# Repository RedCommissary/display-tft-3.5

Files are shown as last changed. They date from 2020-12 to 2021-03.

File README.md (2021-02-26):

## Информационная панель на базе TFT ILI9488 3.5"

Простая HMI панель на базе микроконтроллера STM32 и TFT дисплея с диагональю 3.5", предназначенная для работы в составе различных радиоэлектронных устройствах для вывода различной графической информации. На плате так же установлен пьезокерамический узлучатель (buzzer) и имеется возможность подключить внешнюю клавиатуру через выведенные на разъем I/O, реализованы цепи аппаратного подавления дребезга контактов.

Вид сверху

>

Вид снизу

>

Клавиатура

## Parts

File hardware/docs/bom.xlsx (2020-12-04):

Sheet: HMI-TFT-3.5
Designator | Value | PartNumber | Manufacturer | Quantity | Comment | HelpURL
BF1 |  | MLT-7525 | Jiangsu | 1 | SMD, 7.5x7.5x2.5 mm, 2.7 kHz, 3.6VDC, 80dB, -20...+70°C | https://lcsc.com/product-detail/Buzzers_Jiangsu-Huaneng-Elec-MLT-7525_C95299.html
C1, C7, C9, C10, C11, C12, C13, C15, C16, C17, C18 | 4.7μF | CL10B475KQ8NQNC | Samsung | 11 | Ceramic capacitor, 4.7μF, X7R, ±10%, 6.3V, 603, -55...+125°C | https://www.digikey.com/en/products/detail/samsung-electro-mechanics/CL10B475KQ8NQNC/3887745
C2, C3, C4, C5, C6, C8, C14, C19 | 0.1μF | CL10B104KB8WPND | Samsung | 8 | Ceramic capacitor, 0.1μF, X7R, ±10%, 50V, 603, -55...+125°C | https://www.digikey.com/product-detail/en/samsung-electro-mechanics/CL10B104KB8WPND/1276-CL10B104KB8WPNDCT-ND/11488014
D1 |  | STM32F401CCU6 | STMicroelectronics | 1 | IC microcontroller, 32-Bit, Cortex-M4, 84MHz, 256KB, 64KB, 1.7...3.6V, -40...+85°C, 48-UFQFPN (7x7) | https://www.digikey.com/en/products/detail/stmicroelectronics/STM32F401CCU6/4755971
D2 |  | AP63200WU-7 | Diodes | 1 | DC/DC buck converter, input 3.8...32V, 500kHz, output 1.2...12V, 2A, -40...+85°C, SOT23-6 | https://www.digikey.com/en/products/detail/diodes-incorporated/AP63200WU-7/9858423
L1 | 4.7μH | CD32YP0302-4R7M | YJYCOIN | 1 | Fixed inductor, 4.7μH, ±20%, CD32 series, 1.5A, -40...+125°C | https://lcsc.com/product-detail/New-Arrivals_YJYCOIN-CD32YP0302-4R7M_C492259.html
R1, R2, R4, R8, R10, R12, R15, R20, R22 | 10k | RC0603JR-0710KL | Yageo | 9 | Resistor film, 10k, ±5%, 603, 0.1W, -55...+125°C | https://www.digikey.com/product-detail/en/yageo/RC0603JR-0710KL/311-10KGRCT-ND/729647
R3, R5, R6, R7, R9, R11, R14, R19, R21 | 120R | RC0603JR-07120RL | Yageo | 9 | Resistor film, 120R, ±5%, 603, 0.1W, -55...+125°C | https://www.digikey.com/product-detail/en/yageo/RC0603JR-07120RL/311-120GRCT-ND/729653
R13, R17 | 1k | RC0603JR-071KL | Yageo | 2 | Resistor film, 1k, ±1%, 603, 0.1W, -55...+125°C | https://www.digikey.com/en/products/detail/yageo/RC0603JR-071KL/726677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
R16 | 30k9 | RC0603FR-0730K9L | Yageo | 1 | Resistor film, 30k9, ±1%, 603, 0.1W, -55...+125°C | https://www.digikey.com/en/products/detail/yageo/RC0603FR-0730K9L/727144
R18 | 10k | AC0603FR-0710KL | Yageo | 1 | Resistor film, 10k, ±1%, 603, 0.1W, -55...+125°C | https://www.digikey.com/en/products/detail/yageo/AC0603FR-0710KL/2827814
VD1 |  | 150060VS75000 | Wurth | 1 | LED, 20mA, 2V, 603, -55...+150°C | https://www.digikey.com/product-detail/en/w-rth-elektronik/150060VS75000/732-4980-1-ND/4489904
VD2 |  | 150060YS75000 | Wurth | 1 | LED, 20mA, 2V, 603, -55...+150°C | https://www.digikey.com/product-detail/en/wurth-electronics-inc/150060YS75000/732-4981-1-ND/4489907
VD3 |  | MBR2H100SFT3G | ON Semiconductor | 1 | Schottky diode, 100V, 2A, 840mV, 15pF, SOD-123F, -55...+150°C | https://www.digikey.com/product-detail/en/on-semiconductor/MBR2H100SFT3G/MBR2H100SFT3GOSCT-ND/3462288
VT1, VT2 |  | IRLML0030TRPBF | Infineon Technologies | 2 | MOSFET N-channel transistor, 30V, 5.3A, 2.6nC, 1.3W, 27mOhm, 382pF, SOT-23, -55...+150°C | https://www.digikey.com/en/products/detail/infineon-technologies/IRLML0030TRPBF/2202215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
X1 |  | AFC07-S40ECC-00 | JUSHUO | 1 | Connector, 40pin, 0.5mm, FFC/FPC, Top contact | https://lcsc.com/product-detail/FFC-FPC-Connectors_JUSHUO-AFC07-S40ECC-00_C11097.html
X3 |  | CWF-4R | Connfly | 1 | Connector, 4pin, 2.54mm, 250VAC, 3A | https://www.chipdip.ru/product/cwf-4r-ds1069-4-mr
X4 |  | CWF-6R | Connfly | 1 | Connector, 6pin, 2.54mm, 250VAC, 3A | https://www.chipdip.ru/product/cwf-6r-ds1069-6-mr

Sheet: Keyboard
Designator | Value | PartNumber | Manufacturer | Quantity | Comment | HelpURL
SB1, SB2, SB3, SB4, SB5 |  | FSM2JSMAATR | TE Connectivity | 5 | Tactile button, 6x6mm | https://www.digikey.com/product-detail/en/te-connectivity-alcoswitch-switches/FSM2JSMAATR/450-1792-1-ND/3503931
X1 |  | CWF-6R | Connfly | 1 | Connector, 6pin, 2.54mm, 250VAC, 3A | https://www.chipdip.ru/product/cwf-6r-ds1069-6-mr

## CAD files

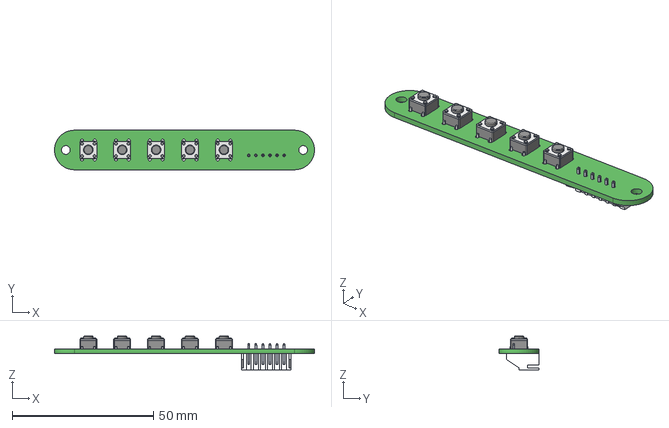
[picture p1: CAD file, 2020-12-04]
hardware/mechanical/3d-keyboard-pcb.step
92.0 x 14.0 x 12.0 mm

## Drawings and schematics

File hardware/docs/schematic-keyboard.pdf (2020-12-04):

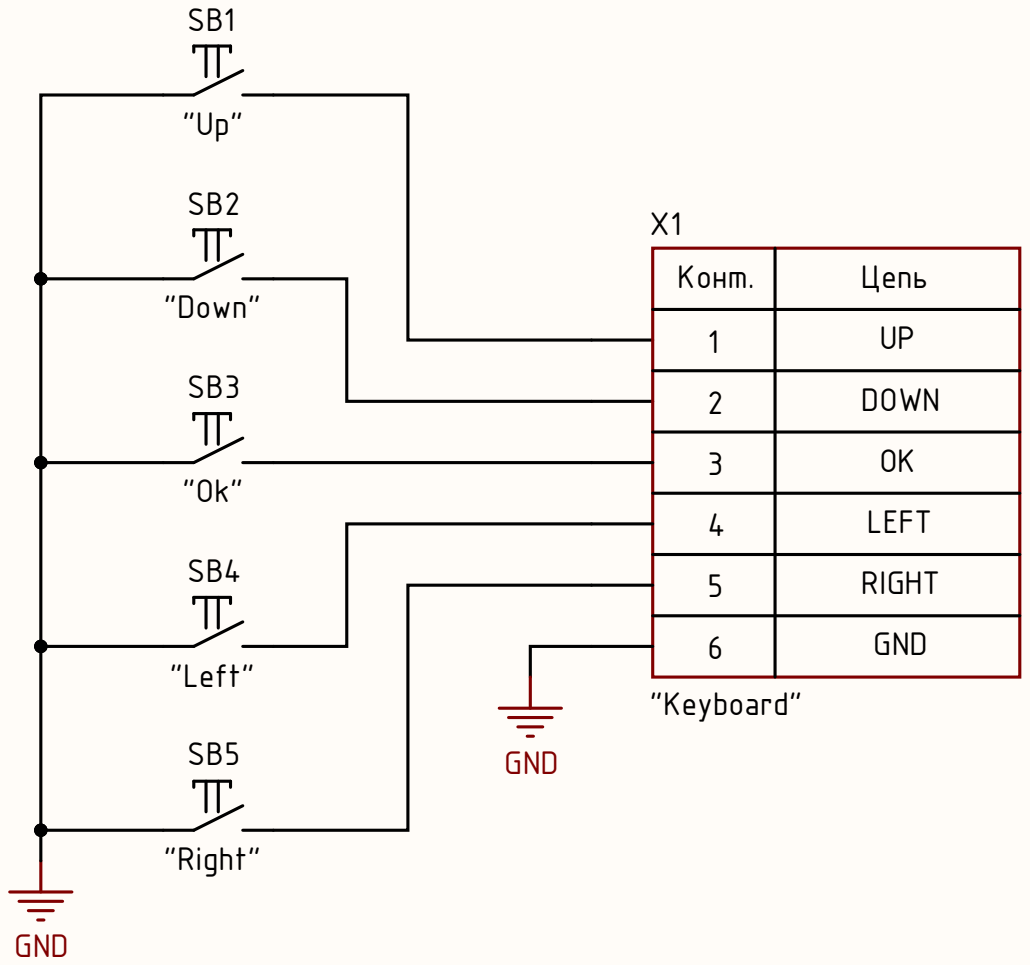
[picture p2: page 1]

"Keyboard" 12 Конт. | Цепь 3456 D O W N

Author Date | Ilya Galki n | Keyboard for HMI pannel with TFT display of 3.5"

Manufacturer Page Total pages

Materials Size page | A3

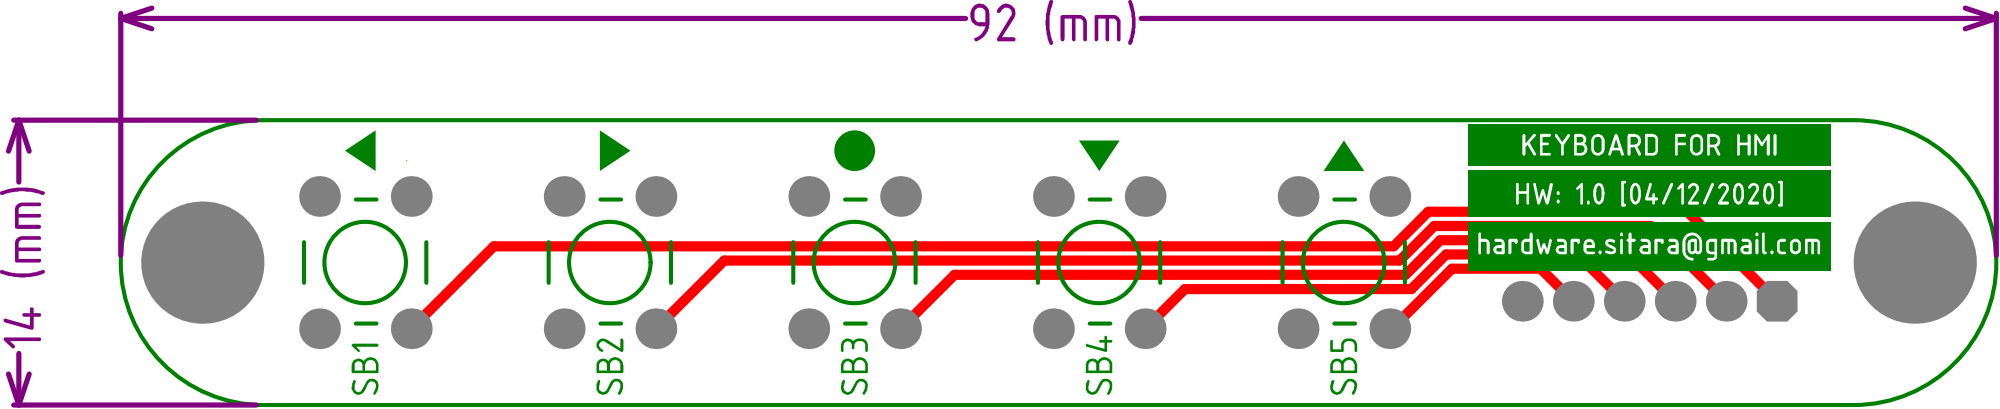
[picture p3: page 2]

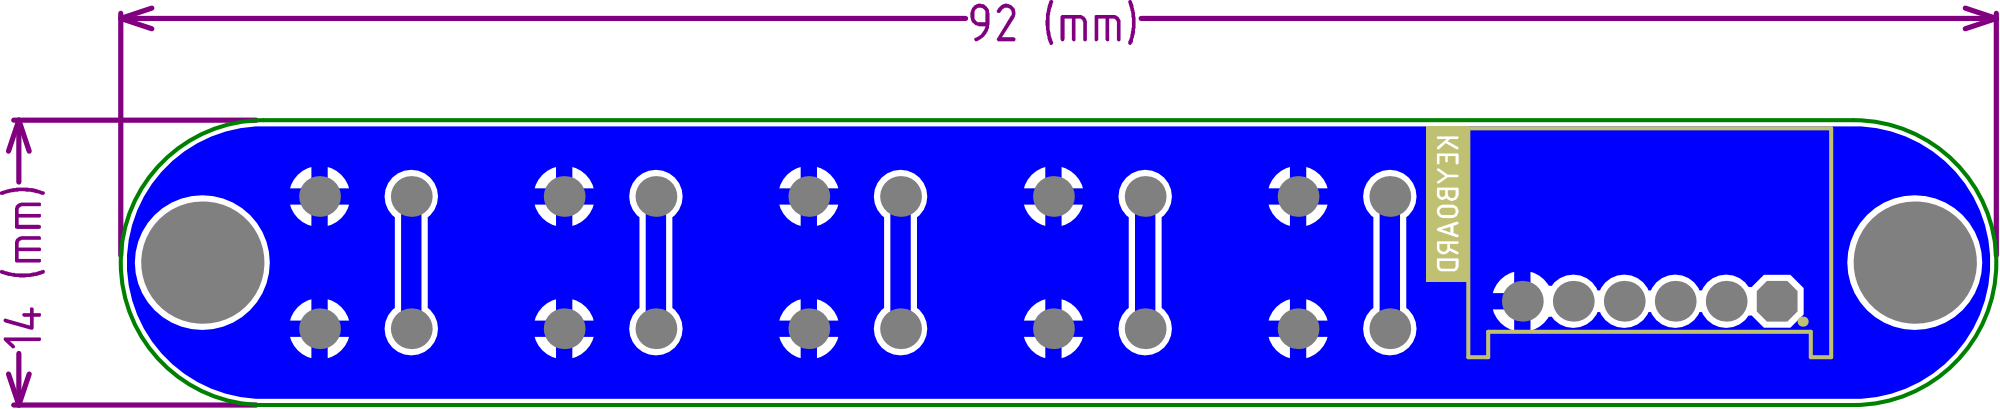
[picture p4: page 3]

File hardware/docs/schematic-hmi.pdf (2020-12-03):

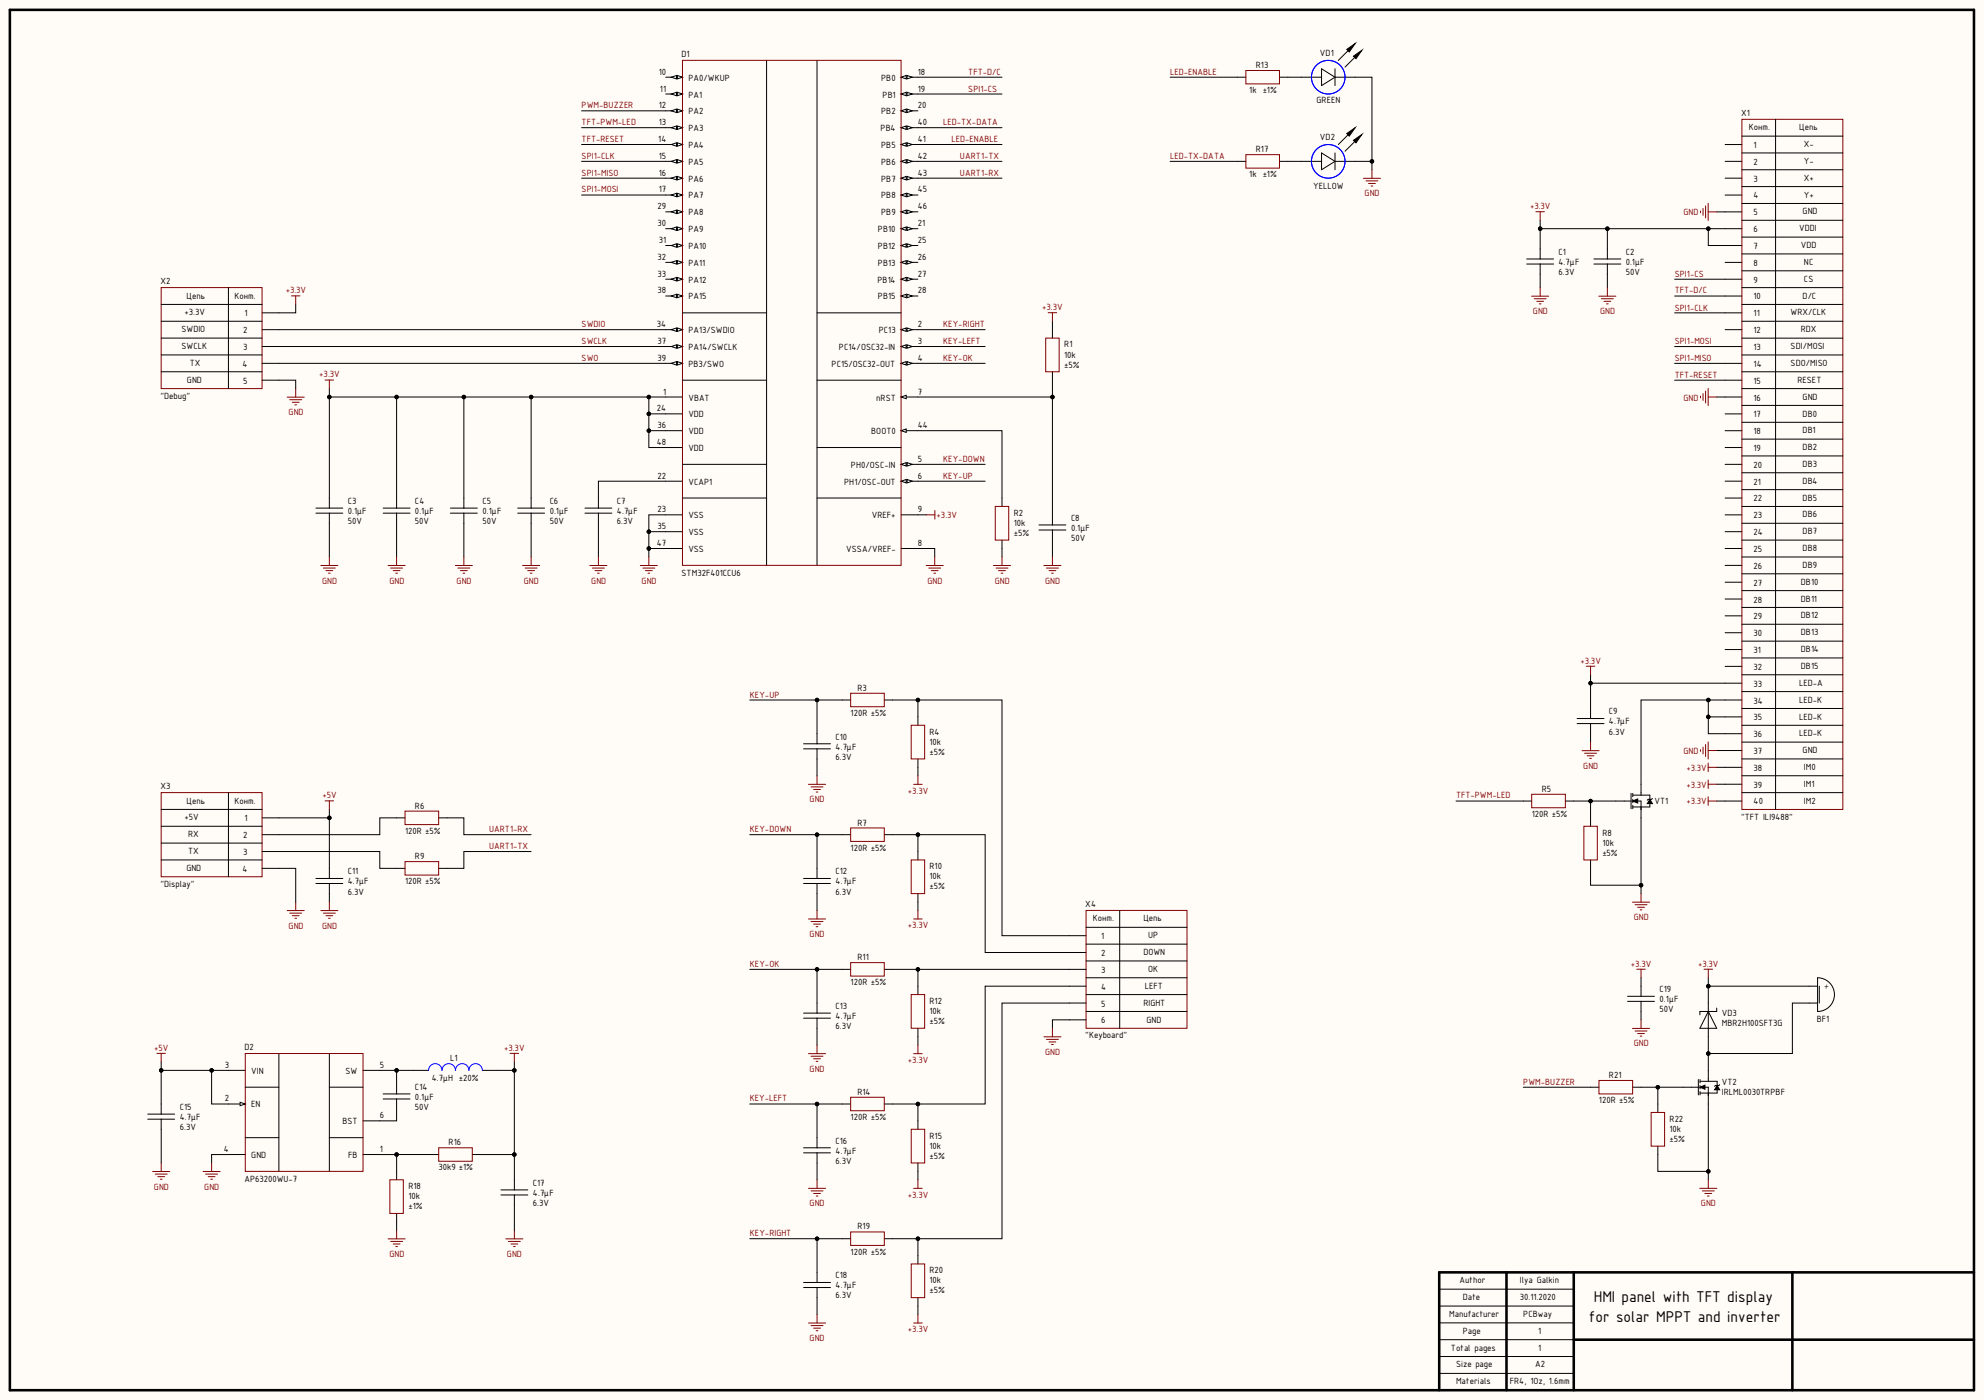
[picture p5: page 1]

Y+ GND

CSD/C

18 | WRX/CLK RDX SDI/MOSI SDO/MISO RESET GND DB0 DB1 DB2 DB3 DB4 DB5 DB6 DB7 DB8 DB9 DB10 DB11 DB12 DB13 DB14 DB15

KEY-LEFT KEY-RIGH

4 8 | 5 KEY-D OWN 6 KEY-U P

S 23 VS VS VS S | VREF+ VS SA/VREF-

33 | LED-A

34 | LED-K

+3.3V | 35 | LED-K

37 | LED-K GND IM0 IM1 IM2
36

38
3940

Цепь | Конт .

"Keyboard" 12 Конт. | Цепь 3456 D O W N

HMI panel with TFT display
for solar MPPT and inverter

Manufacturer Page Total pages

Materials Size page | A2

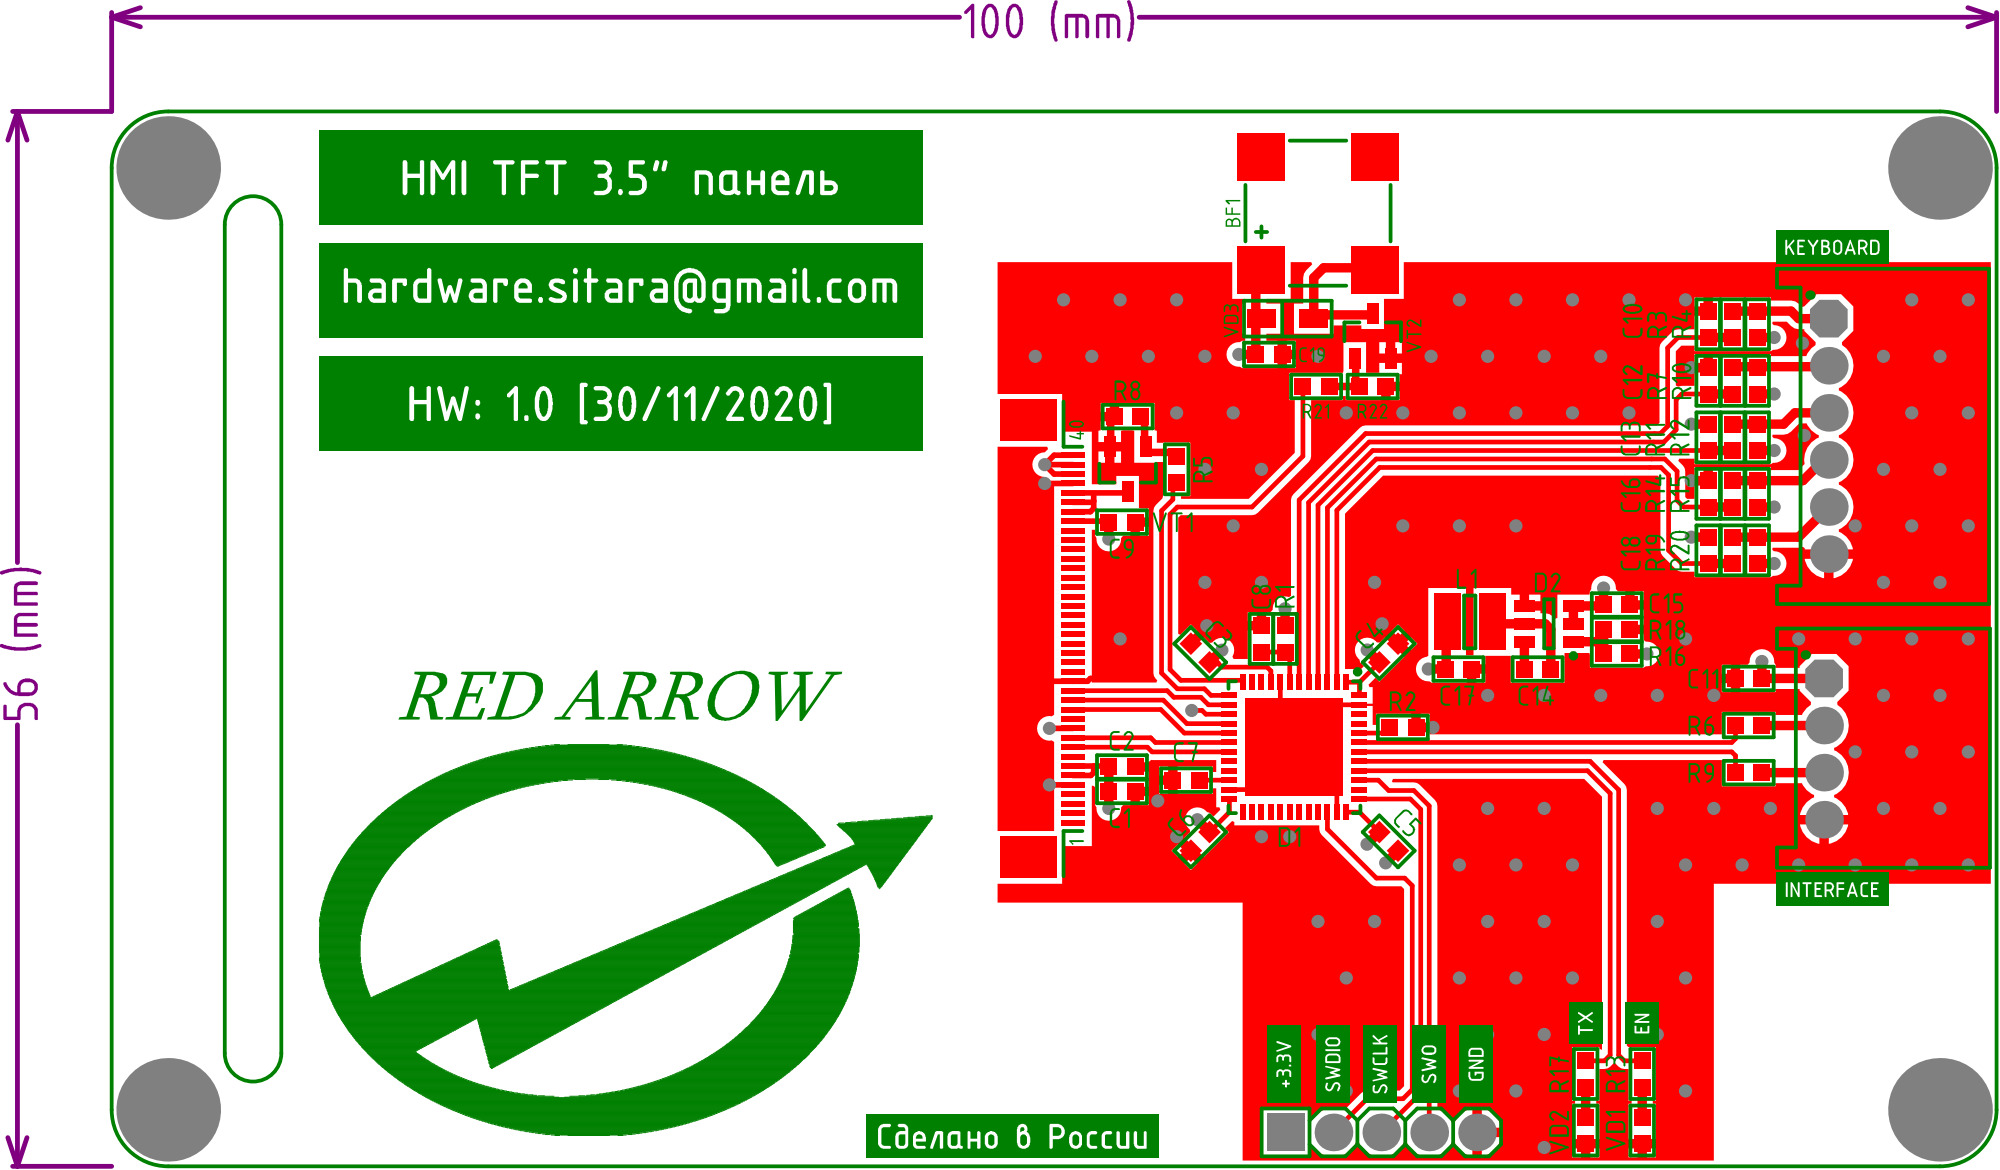
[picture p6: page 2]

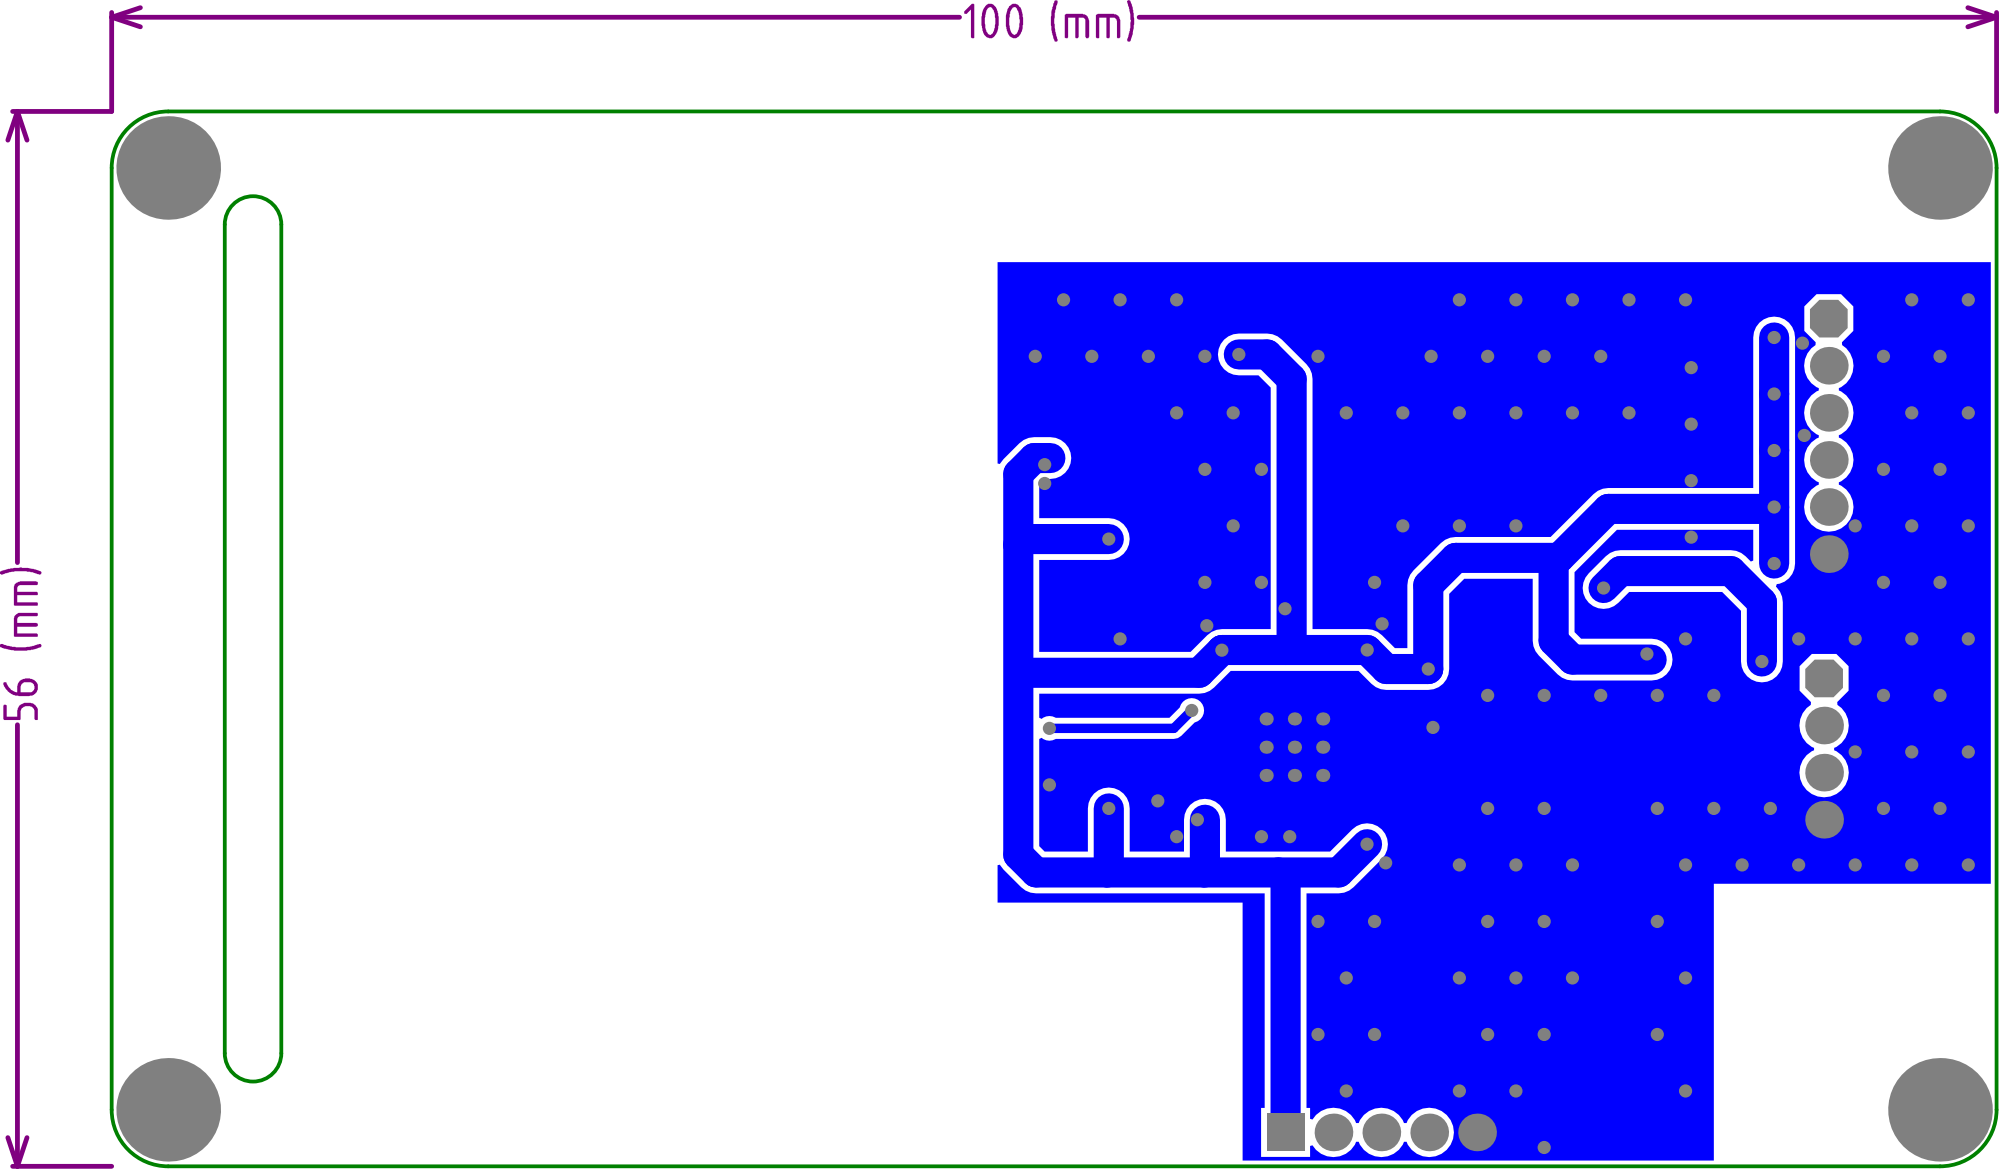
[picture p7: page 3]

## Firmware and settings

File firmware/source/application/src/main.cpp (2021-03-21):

/********************************************************************************
 * project     HMI panel of the MCU STM32F401CCU6 and TFT ILI9488 (SPI)         *
 *                                                                              *
 * file        main.cpp                                                         *
 * author      @RedCommissary                                                   *
 * date        10.02.2021                                                       *
 *                                                                              *
 ********************************************************************************/

/********************************************************************************
 * Include 
 ********************************************************************************/

#include "main.h"
#include "lvgl.h"
#include "ili9488.h"

void lv_port_disp_init();
void disp_flush (lv_disp_drv_t * disp_drv, const lv_area_t * area, lv_color_t * color_p);
void StartDisplayProcessing();
void lv_example_arc_1();

int main() {
    Application::Init();
    StartDisplayProcessing();

    lv_init();
    lv_port_disp_init();
    lv_example_arc_1();

    while(1){
        Delay::Set(5);
        lv_tick_inc(5);
    }
}

/********************************************************************************
 * Function
 ********************************************************************************/

void lv_port_disp_init() {
    ILI9488::Init();
    ILI9488::SetBrightness(80);

    static lv_disp_buf_t draw_buf_dsc;
    static lv_color_t draw_buf[LV_HOR_RES_MAX * 10];                          
    lv_disp_buf_init(&draw_buf_dsc, draw_buf, NULL, LV_HOR_RES_MAX * 10);   


    lv_disp_drv_t disp_drv;                         
    lv_disp_drv_init(&disp_drv);                    
    disp_drv.hor_res = 480;
    disp_drv.ver_res = 320;
    disp_drv.flush_cb = disp_flush;
    disp_drv.buffer = &draw_buf_dsc;
    lv_disp_drv_register(&disp_drv);
}

void disp_flush (lv_disp_drv_t * disp_drv, const lv_area_t * area, lv_color_t * color_p) {
    uint16_t xStart = area->x1;
    uint16_t xEnd = area->x2;
    uint16_t yStart = area->y1;
    uint16_t yEnd = area->y2;
    uint16_t color = lv_color_to16(*color_p);

    ILI9488::DrawFill(xStart, yStart, xEnd, yEnd, color);

    lv_disp_flush_ready(disp_drv);
}

/********************************************************************************
 * Display processing
 ********************************************************************************/

void StartDisplayProcessing() {
    RCC->APB1ENR |= RCC_APB1ENR_TIM3EN;     

    TIM3->PSC = 42-1;
    TIM3->ARR = 200;
    TIM3->DIER |= TIM_DIER_UIE;
    TIM3->CR1  |= TIM_CR1_CEN;

    NVIC_EnableIRQ(TIM3_IRQn);
}

void sTim3::handler (void) {
    TIM3->SR &= ~TIM_SR_UIF;
    lv_task_handler();
}

/********************************************************************************
 * Example for GUI
 ********************************************************************************/

void lv_example_arc_1() {
    lv_obj_t * arc = lv_arc_create(lv_scr_act(), NULL);
    lv_arc_set_end_angle(arc, 200);
    lv_obj_set_size(arc, 150, 150);
    lv_obj_align(arc, NULL, LV_ALIGN_CENTER, 0, 0);
}

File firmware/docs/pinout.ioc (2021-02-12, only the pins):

Mcu.UserName=STM32F401CCUx
PA13.Signal=SYS_JTMS-SWDIO
PA14.Signal=SYS_JTCK-SWCLK
PA2.GPIO_Label=TIM2-CH3-PWM-BUZZER
PA2.Signal=S_TIM2_CH3
PA3.GPIO_Label=TIM5-CH4-TFT-LED
PA3.Signal=S_TIM5_CH4
PA4.GPIO_Label=TFT-RESET
PA4.Signal=GPIO_Output
PA5.Signal=SPI1_SCK
PA6.Signal=SPI1_MISO
PA7.Signal=SPI1_MOSI
PB0.GPIO_Label=TFT-D/C
PB0.Signal=GPIO_Output
PB1.GPIO_Label=SPI1-CS
PB1.Signal=GPIO_Output
PB3.Signal=SYS_JTDO-SWO
PB4.GPIO_Label=LED-TX-DATA
PB4.Signal=GPIO_Output
PB5.GPIO_Label=LED-ENABLE
PB5.Signal=GPIO_Output
PB6.Signal=USART1_TX
PB7.Signal=USART1_RX
PC13-ANTI_TAMP.GPIO_Label=KEY-RIGHT
PC13-ANTI_TAMP.Signal=GPXTI13
PC14-OSC32_IN.GPIO_Label=KEY-LEFT
PC14-OSC32_IN.Signal=GPXTI14
PC15-OSC32_OUT.GPIO_Label=KEY-OK
PC15-OSC32_OUT.Signal=GPXTI15

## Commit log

2020-11-20 docs: Добавил даташит на контроллер дисплея ILI9488
2020-11-20 new: Запустил дисплей ILI9488, протестировал и определил схему
2020-11-30 new: Завершил принципиальную схему HMI панели
    [hmi-tft-3.5.PrjPcb, hmi.SchDoc, pcb.PcbDoc]
2020-11-30 new: Выполнил трассировку печатной платы, завершил проект
    [hmi-tft-3.5.PrjPcb, hmi.SchDoc]
2020-11-30 docs: Добавил pinout по схеме для микроконтроллера
2020-11-30 docs: Сгенерировал КД: схема, вом, 3d модель, gerber файлы
    [bom.xlsx]
2020-12-03 new: Добавил буззер в проект и выгрузил КД с изменениями
    [bom.xlsx, hmi-tft-3.5.PrjPcb, hmi.SchDoc]
2020-12-04 new: Завершил проект клавиатуры для HMI панели
    [hmi-tft-3.5.PrjPcb, hmi.SchDoc, keyboard-for-hmi.PrjPcb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]
2020-12-04 docs: Сгенерировал КД для клавиатуры: схема, вом, 3d модель, gerber файлы
    [3d-keyboard-pcb.step, bom.xlsx]
2021-02-10 new: Проверил новые HMI. Добавил функцию отрисовки прямоугольника
2021-02-10 new: Перевел проект на cmsis голый, написал стартап и линкер
2021-02-10 new: Выполнил настройку всех используемых портов ввода-вывода
2021-02-10 fix: Скорректировал библиотек GPIO под работу с STM32F401CC
2021-02-10 new: Реализовал внешние прерывания от кнопок и фильтр событий
2021-02-10 new: Реализовал настройку системы тактирования и управление бузером
2021-02-12 new: Добавил реализацию аппаратных задержек на SysTick
2021-02-12 new: Завершил драйвер для TFT дислея на ILI9488 по SPI
2021-02-12 new: Добавил основной класс для логики приложения
2021-02-12 refactor: Разбил класс periphery на отдельный библиотеки-классы в файлах
2021-02-26 docs: Добавил описание для проекта HMI панели
2021-02-26 fix: Внес правки в размер платы и расположение выреза под шлейф
    [hmi-tft-3.5.PrjPcb, hmi.SchDoc]
2021-02-27 docs: Добавил исключения для дебаг файлов и папкм build
2021-02-27 docs: Портировал проект на новую машину под новые настройки
2021-02-27 new: Написал драйвер для SPI. Есть проблема с отправкой байта
2021-02-27 docs: Добавил даташит и RM для используемого STM32F401CCU6
2021-02-28 new: Исправил ошибку с CS, добавил флаги RXNE и BSY
2021-02-28 new: Завершил драйвер для ILI9488 и базовые функции отрисовки
2021-02-28 new: Реализовал базовую работу с TFT дисплеем
2021-03-02 refactor: Преобразовал работу с графикой в отдельную библиотеку Display
2021-03-02 refactor: Убрал прослойку с настройкой i/o в виде файла Pinout
2021-03-02 new: Реализовал класс для настройки таймеров
2021-03-02 new: Реализовал класс настройки и управления подстветкой дисплея
2021-03-02 refactor: Корректно разделил проект на уровень драйверов и приложения: - убрал отдельно прослойку настройки выводов Pinout; - перенес работу со светодиодами и бузером из драйверов в приложение; - вын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
2021-03-02 refactor: Вынес delay в отдельную системную папку. BSP перенес в хедеры
2021-03-02 new: Добавил пару семисегментных шрифтов
2021-03-02 new: Реализовал методы отрисовки символа и строки текста
2021-03-04 refactor: Перенес работу с подсветкой внутрь драйвера ILI9488
2021-03-21 new: Первая попытка запустить LVGL, есть проблемы с виджетами
